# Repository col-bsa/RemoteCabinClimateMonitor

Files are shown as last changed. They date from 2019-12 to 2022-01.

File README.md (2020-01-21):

# RemoteCabinClimateMonitor

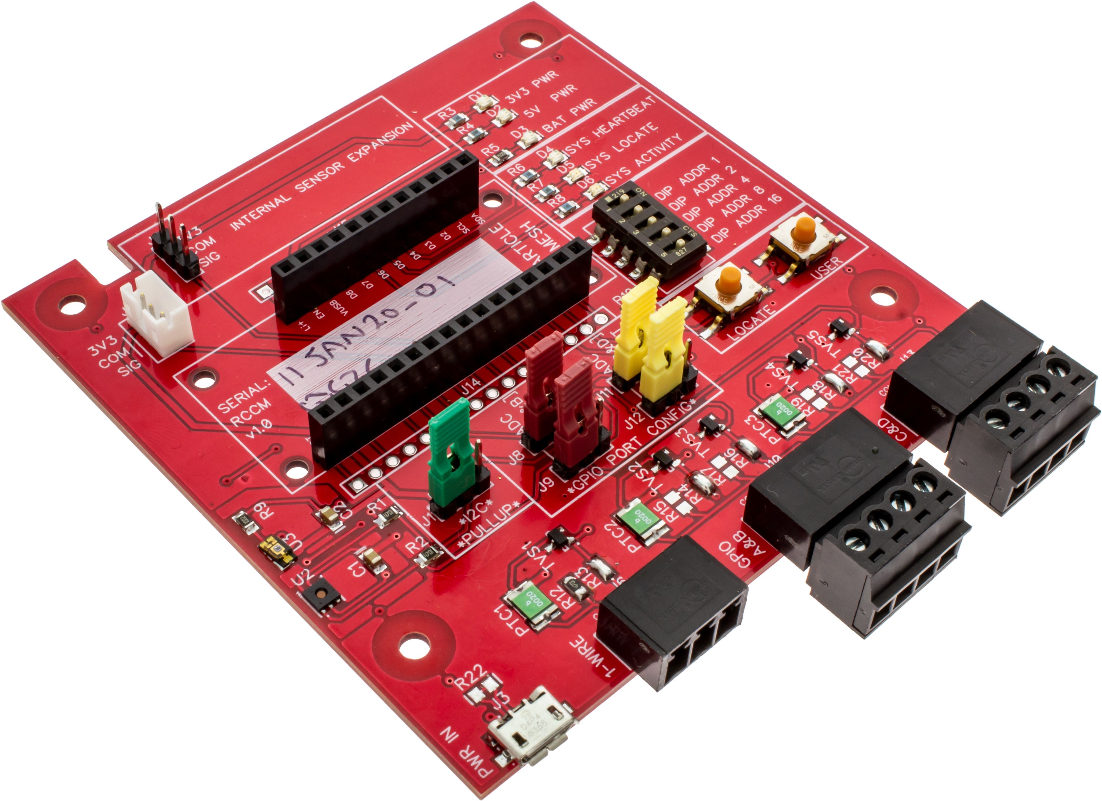
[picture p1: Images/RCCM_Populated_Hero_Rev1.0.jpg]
Remote Cabin Climate Monitor


A Particle Mesh based environmental sensor board, whose primary purpose is to monitor unoccupied cabin temperatures at Resica Falls Scout Reservation.

Repository Contents
-------------------

* **/Hardware** - DipTrace Schematic & PCB Layout
* **/Software** - 
* **/Images** -

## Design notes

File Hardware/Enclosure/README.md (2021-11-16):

# RCCM Enclosure

Designed in Fusion360.

Designed for FDM 3D Printing:
- Prusa MK3S
- Prusament PLA (Galaxy Black)
- Prusa Slicer 0.2mm DETAIL Preset

Current Design:
https://a360.co/3HgQXV9

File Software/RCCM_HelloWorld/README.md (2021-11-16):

# RCCM_HelloWorld

Quick and dirty firmware for "end of line" function RCCM PCB finctionality.

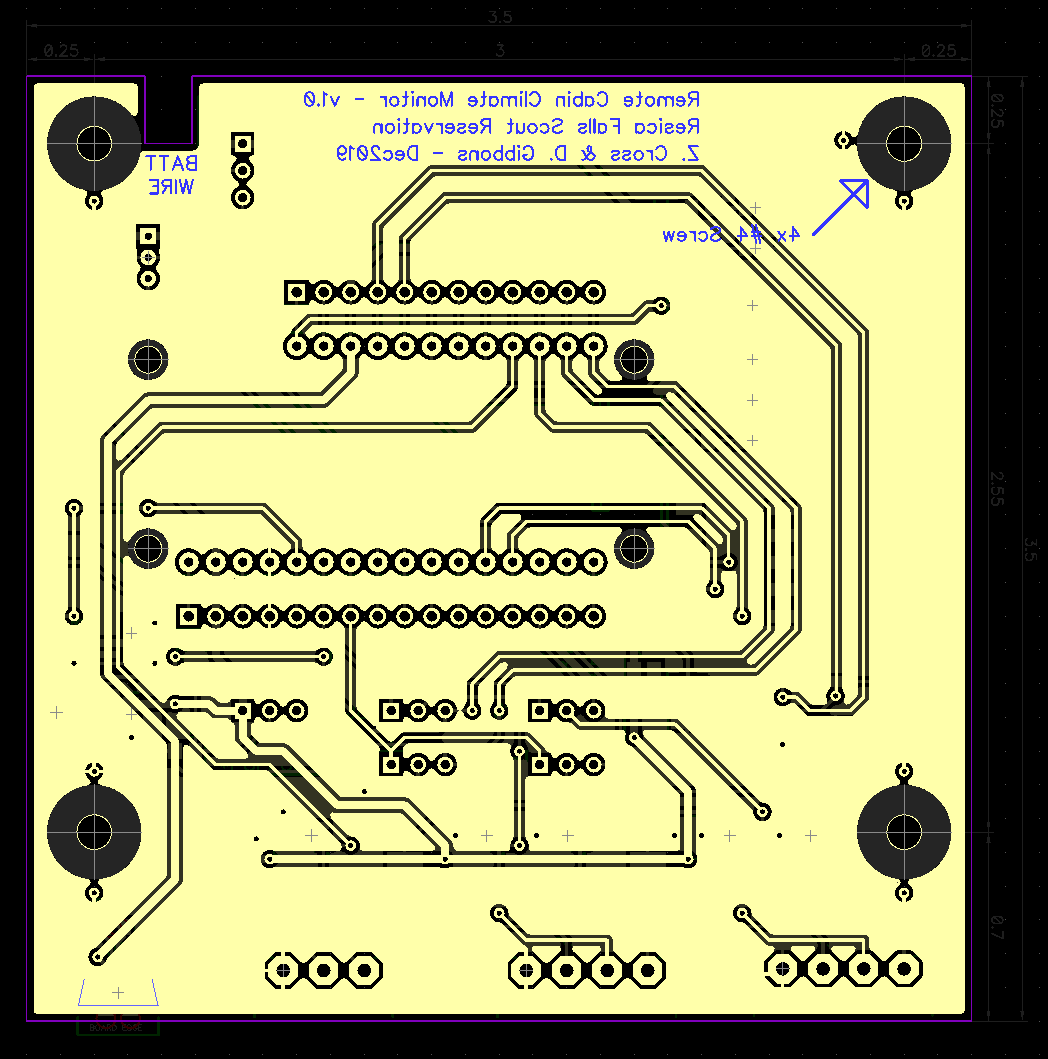
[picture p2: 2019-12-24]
Images/RCCM_PCB_Layout_Back_Rev1.0.png

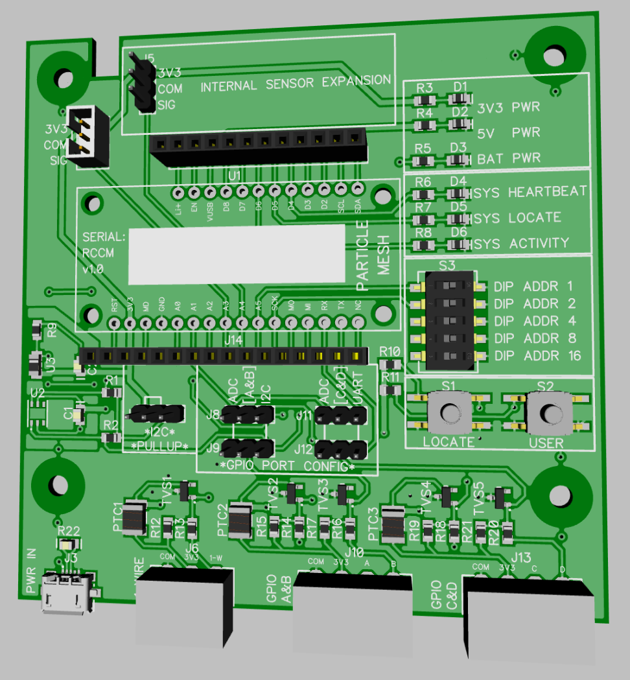
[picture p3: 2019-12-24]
Images/RCCM_PCB_3DModel_Front_Rev1.0.png

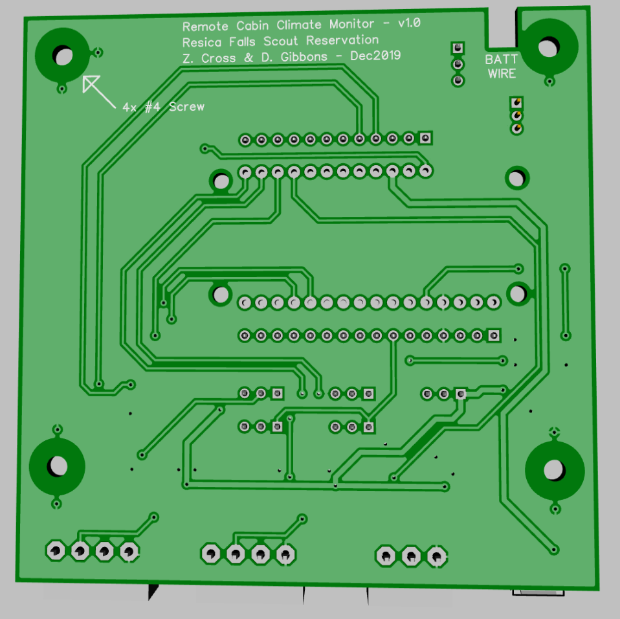
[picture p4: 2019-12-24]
Images/RCCM_PCB_3DModel_Back_Rev1.0.png

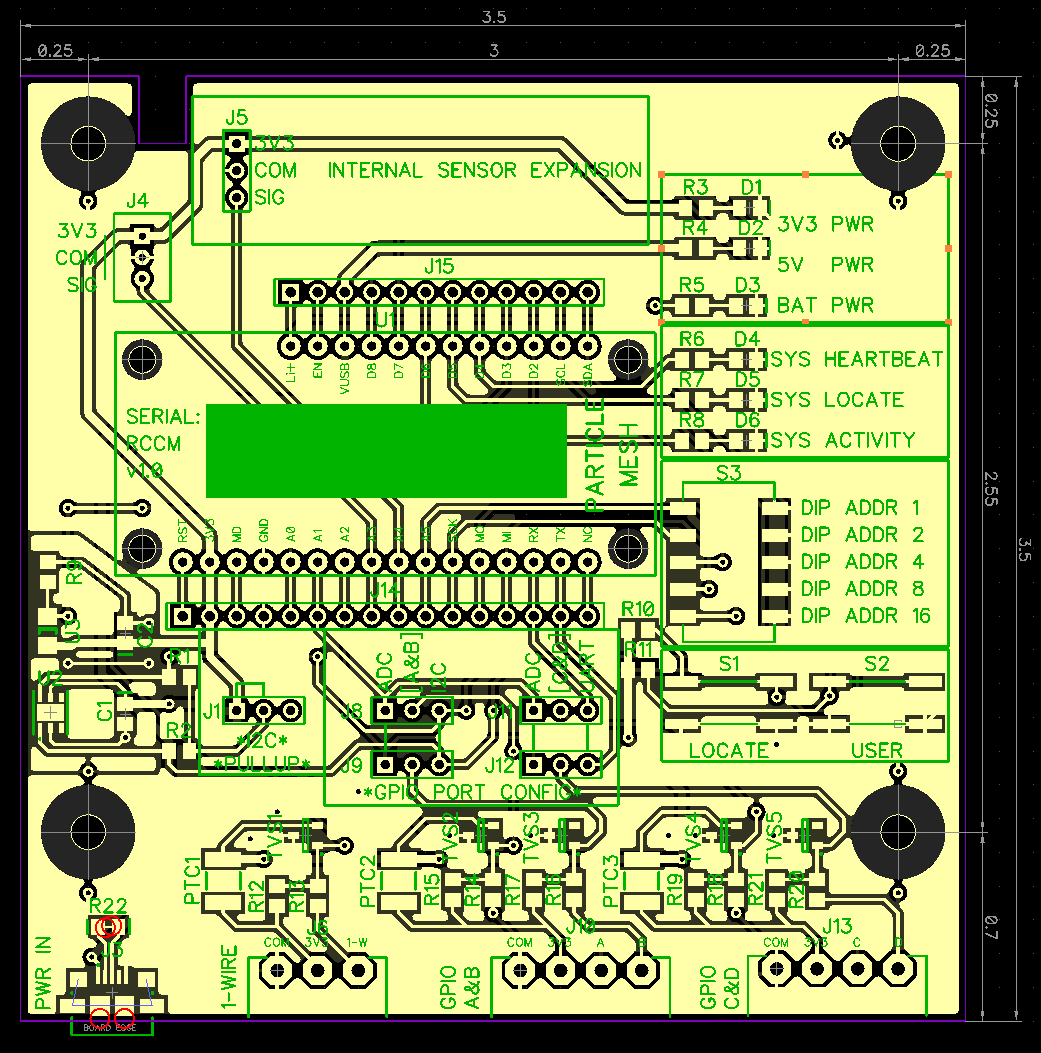
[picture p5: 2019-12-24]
Images/RCCM_PCB_Layout_Front_Rev1.0.png

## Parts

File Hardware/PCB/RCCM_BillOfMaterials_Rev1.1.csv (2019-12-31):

# | Name | RefDes | Manufacturer | Mfr Pn | Cost
1 | CAP CER 0.1UF 100V X7R 0805 | C1 | Samsung Electro-Mechanics | CL21B104KCFNNNE | 0.1
2 | CAP CER 0.1UF 100V X7R 0805 | C2 | Samsung Electro-Mechanics | CL21B104KCFNNNE | 0.1
3 | LED YELLOW/GREEN CLEAR 0805 SMD | D1 | Everlight Electronics Co Ltd | 17-21SYGC/S530-E2/TR8 | 0.29
4 | LED YELLOW/GREEN CLEAR 0805 SMD | D2 | Everlight Electronics Co Ltd | 17-21SYGC/S530-E2/TR8 | 0.29
5 | LED YELLOW/GREEN CLEAR 0805 SMD | D3 | Everlight Electronics Co Ltd | 17-21SYGC/S530-E2/TR8 | 0.29
6 | LED YELLOW/GREEN CLEAR 0805 SMD | D4 | Everlight Electronics Co Ltd | 17-21SYGC/S530-E2/TR8 | 0.29
7 | LED ORANGE-RED 0805 SMD | D5 | Dialight | 5990120007F | 0.38
8 | LED ORANGE-RED 0805 SMD | D6 | Dialight | 5990120007F | 0.38
9 | S1012EC-03-ND | J1 | Sullins Connector Solutions | PREC003SAAN-RC | 0.09
10 | TERM BLOCK PLUG 4POS STR 3.81MM | J2 | Molex | 0395100004 | 1.71
11 | CONN RCPT USB2.0 MICRO B SMD R/A | J3 | TE Connectivity | 1981568-1 | 1.86
12 | CONN HEADER VERT 3POS 2MM | J4 | JST Sales America Inc. | B3B-PH-K-S(LF)(SN) | 0.19
13 | S1012EC-03-ND | J5 | Sullins Connector Solutions | PREC003SAAN-RC | 0.09
14 | TERM BLOCK HDR 3POS 90DEG 3.81MM BLACK | J6 | Molex | 0395121003 | 1.03
15 | TERM BLOCK PLUG 3POS STR 3.81MM BLACK | J7 | Molex | 0395100003 | 1.25
16 | S1012EC-03-ND | J8 | Sullins Connector Solutions | PREC003SAAN-RC | 0.09
17 | S1012EC-03-ND | J9 | Sullins Connector Solutions | PREC003SAAN-RC | 0.09
18 | TERM BLOCK HDR 4POS 90DEG 3.81MM BLACK | J10 | Molex | 0395121004 | 1.41
19 | S1012EC-03-ND | J11 | Sullins Connector Solutions | PREC003SAAN-RC | 0.09
20 | S1012EC-03-ND | J12 | Sullins Connector Solutions | PREC003SAAN-RC | 0.09
21 | TERM BLOCK HDR 4POS 90DEG 3.81MM BLACK | J13 | Molex | 0395121004 | 1.41
22 | CONN HDR 16POS 0.1 TIN PCB | J14 | Sullins | PPTC161LFBN-RC | 0.98
23 | CONN HDR 12POS 0.1 TIN PCB | J15 | Sullins | PPTC121LFBN-RC | 0.78
24 | TERM BLOCK PLUG 4POS STR 3.81MM | J16 | Molex | 0395100004 | 1.71
25 | CONN SHUNT | JMP1 | Samtec Inc. | SNT-100-BK-T | 0.21
26 | CONN SHUNT | JMP2 | Samtec Inc. | SNT-100-BK-T | 0.21
27 | CONN SHUNT | JMP3 | Samtec Inc. | SNT-100-BK-T | 0.21
28 | CONN SHUNT | JMP4 | Samtec Inc. | SNT-100-BK-T | 0.21
29 | CONN SHUNT | JMP5 | Samtec Inc. | SNT-100-BK-T | 0.21
30 | PTC RESET FUSE 30V 200MA 1812 | PTC1 | Littelfuse Inc. | Fuse | 0.42
31 | PTC RESET FUSE 30V 200MA 1812 | PTC2 | Littelfuse Inc. | Fuse | 0.42
32 | PTC RESET FUSE 30V 200MA 1812 | PTC3 | Littelfuse Inc. | Fuse | 0.42
33 | CRGH0805 1% 4K7 0.33W | R1 | TE Connectivity Passive Product | CRGH0805F4K7 | 0.1
34 | CRGH0805 1% 4K7 0.33W | R2 | TE Connectivity Passive Product | CRGH0805F4K7 | 0.1
35 | 130 Ohms ±1% 0.25W, 1/4W Chip Resistor 0805 | R3 | KOA Speer Electronics, Inc. | RK73H2ATTD1300F | 0.1
36 | 300 Ohms ±1% 0.25W, 1/4W Chip Resistor 0805 | R4 | KOA Speer Electronics, Inc. | RK73H2ATTD3000F | 0.1
37 | RES SMD 150 OHM 1% 1/3W 0805 | R5 | TE Connectivity Passive Product | CRGH0805F150R | 0.1
38 | 130 Ohms ±1% 0.25W, 1/4W Chip Resistor 0805 | R6 | KOA Speer Electronics, Inc. | RK73H2ATTD1300F | 0.1
39 | 130 Ohms ±1% 0.25W, 1/4W Chip Resistor 0805 | R7 | KOA Speer Electronics, Inc. | RK73H2ATTD1300F | 0.1
40 | 130 Ohms ±1% 0.25W, 1/4W Chip Resistor 0805 | R8 | KOA Speer Electronics, Inc. | RK73H2ATTD1300F | 0.1
41 | RES SMD 10K OHM 1% 1/3W 0805 | R9 | TE Connectivity Passive Product | CRGH0805F10K | 0.11
42 | RES SMD 10K OHM 1% 1/3W 0805 | R10 | TE Connectivity Passive Product | CRGH0805F10K | 0.11
43 | RES SMD 10K OHM 1% 1/3W 0805 | R11 | TE Connectivity Passive Product | CRGH0805F10K | 0.11
44 | CRGH0805 1% 4K7 0.33W | R12 | TE Connectivity Passive Product | CRGH0805F4K7 | 0.1
45 | RES SMD 10K OHM 1% 1/3W 0805 | R13 | TE Connectivity Passive Product | CRGH0805F10K | 0.11
46 | RES SMD 10K OHM 1% 1/3W 0805 | R14 | TE Connectivity Passive Product | CRGH0805F10K | 0.11
47 | RES SMD 10K OHM 1% 1/3W 0805 | R15 | TE Connectivity Passive Product | CRGH0805F10K | 0.11
48 | RES SMD 10K OHM 1% 1/3W 0805 | R16 | TE Connectivity Passive Product | CRGH0805F10K | 0.11
49 | RES SMD 10K OHM 1% 1/3W 0805 | R17 | TE Connectivity Passive Product | CRGH0805F10K | 0.11
50 | RES SMD 10K OHM 1% 1/3W 0805 | R18 | TE Connectivity Passive Product | CRGH0805F10K | 0.11
51 | RES SMD 10K OHM 1% 1/3W 0805 | R19 | TE Connectivity Passive Product | CRGH0805F10K | 0.11
52 | RES SMD 10K OHM 1% 1/3W 0805 | R20 | TE Connectivity Passive Product | CRGH0805F10K | 0.11
53 | RES SMD 10K OHM 1% 1/3W 0805 | R21 | TE Connectivity Passive Product | CRGH0805F10K | 0.11
54 | JMP_0805 | R22
55 | SWITCH TACTILE SPST-NO 0.01A 32V | S1 | C&K | KSC443G70SHLFG | 0.87
56 | SWITCH TACTILE SPST-NO 0.01A 32V | S2 | C&K | KSC443G70SHLFG | 0.87
57 | SWITCH SLIDE DIP SPST 100MA 20V | S3 | CTS Electrocomponents | 219-5MST | 0.82
58 | TVS DIODE 3.3V 10V SOT323 | TVS1 | Diodes Incorporated | D1213A-01W-7 | 0.36
59 | TVS DIODE 3.3V 10V SOT323 | TVS2 | Diodes Incorporated | D1213A-01W-7 | 0.36
60 | TVS DIODE 3.3V 10V SOT323 | TVS3 | Diodes Incorporated | D1213A-01W-7 | 0.36
61 | TVS DIODE 3.3V 10V SOT323 | TVS4 | Diodes Incorporated | D1213A-01W-7 | 0.36
62 | TVS DIODE 3.3V 10V SOT323 | TVS5 | Diodes Incorporated | D1213A-01W-7 | 0.36
63 | Particle Xenon IoT Development Board | U1 | Particle | WRL-15070 | 15
64 | SENS HUMID/TEMP 3.6V I2C 3% 6DFN | U2 | Silicon Labs | SI7021-A20-GMR | 3.06
65 | SENSOR PHOTO 570NM TOP VIEW 1206 | U3 | Vishay Semiconductor Opto Division | TEMT6000X01 | 1.53
66 | SparkFun OpenPIR | U4 | SparkFun | SEN-1396 | 15.95
67 | JST Jumper 3 Wire Assembly | U5 | SparkFun | PRT-09915 | 1.50
68 | Lithium Ion Battery - 2Ah | Ux | SparkFun | PRT-13855 | 12.95

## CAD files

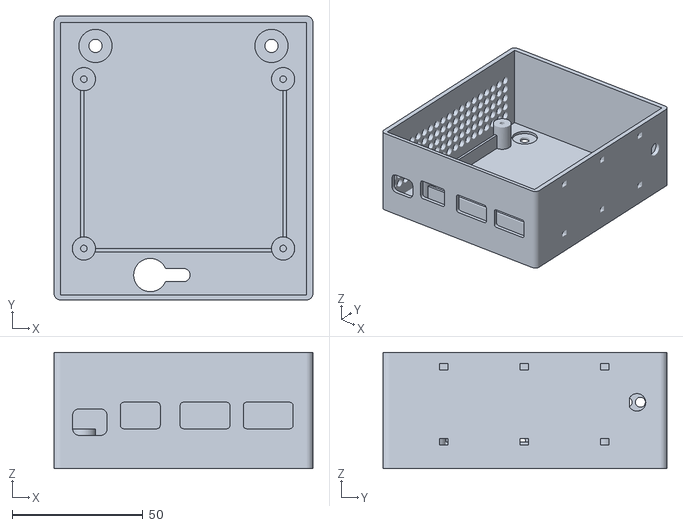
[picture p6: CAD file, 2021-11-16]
Hardware/Enclosure/RCCM_Enclosure_Main Bosy.stl
99.1 x 108.6 x 44.5

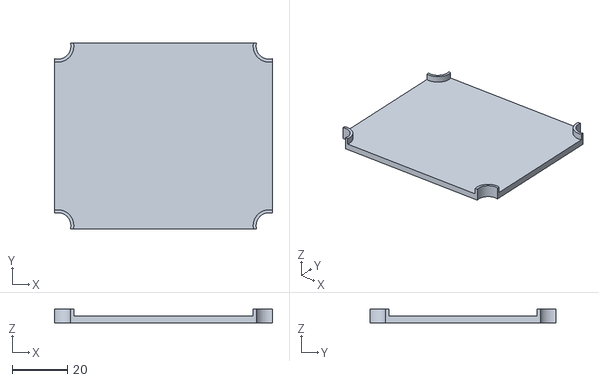
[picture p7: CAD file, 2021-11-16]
Hardware/Enclosure/RCCM_Enclosure_Battery Cover.stl
78.7 x 67.3 x 5.08

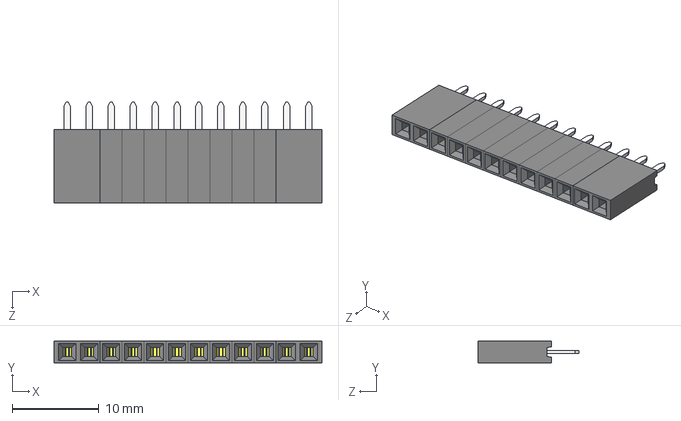
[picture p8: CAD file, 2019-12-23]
Hardware/PCB/Component_3D_Models_And_Libraries/hdrf-1x12t_2.54_31x3.step
31.0 x 2.50 x 11.7 mm

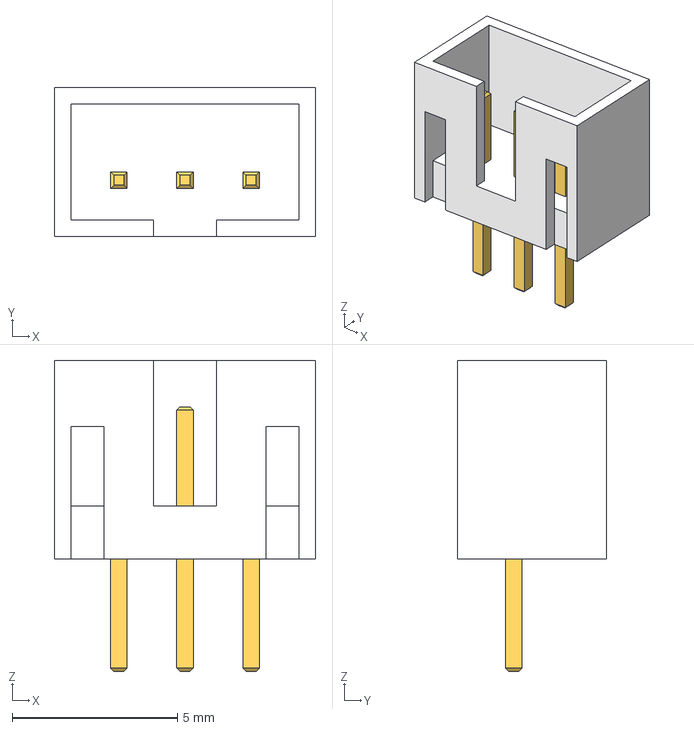
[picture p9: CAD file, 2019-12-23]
Hardware/PCB/Component_3D_Models_And_Libraries/Misc/JST Socket 3 Pin.step
7.90 x 4.50 x 9.40 mm

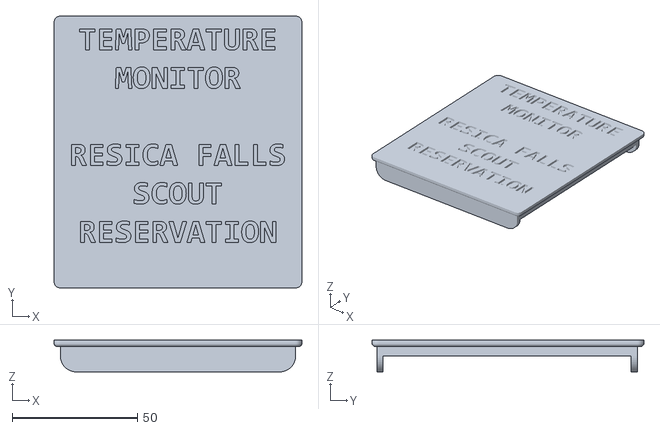
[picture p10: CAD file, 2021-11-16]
Hardware/Enclosure/RCCM_Enclosure_Lid.stl
99.1 x 108.6 x 12.7

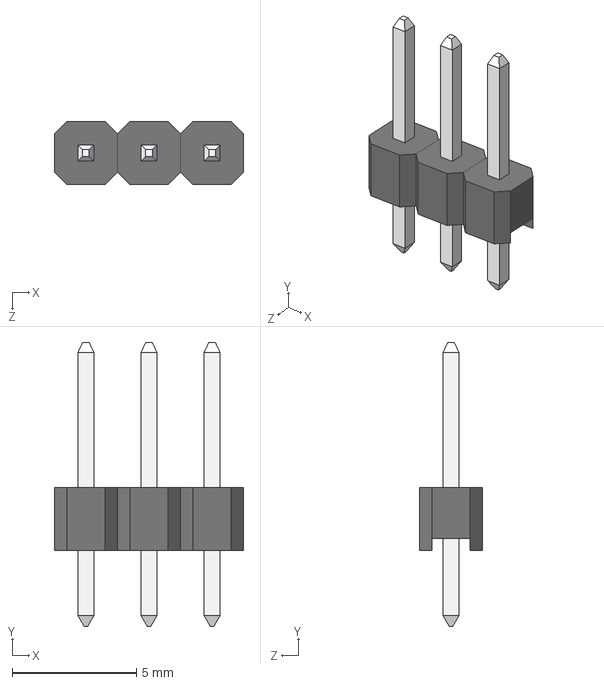
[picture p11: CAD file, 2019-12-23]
Hardware/PCB/Component_3D_Models_And_Libraries/PREC003SAAN-RC.STEP
7.62 x 11.4 x 2.54 mm
1 row end bumps format x 3

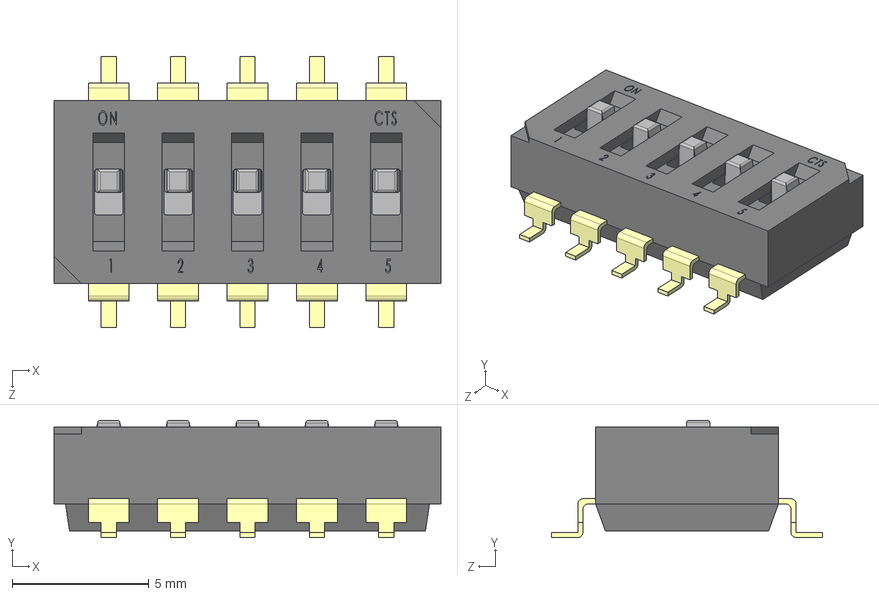
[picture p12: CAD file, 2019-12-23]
Hardware/PCB/Component_3D_Models_And_Libraries/219-5poles.stp
14.2 x 4.30 x 9.91 mm

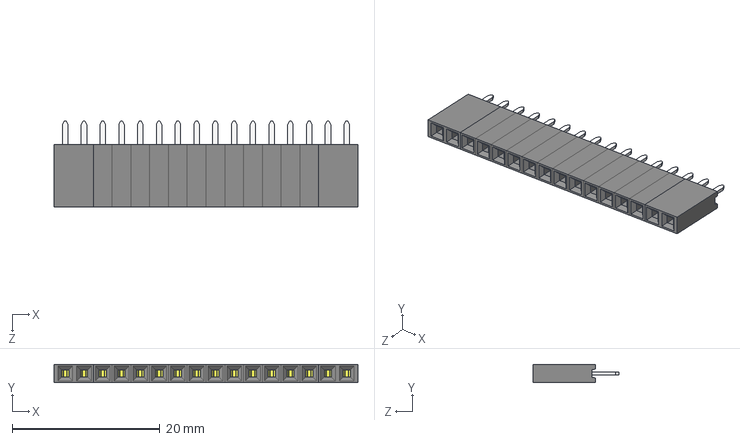
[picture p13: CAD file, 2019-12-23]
Hardware/PCB/Component_3D_Models_And_Libraries/hdrf-1x16t_2.54_41x3.step
41.1 x 2.50 x 11.7 mm

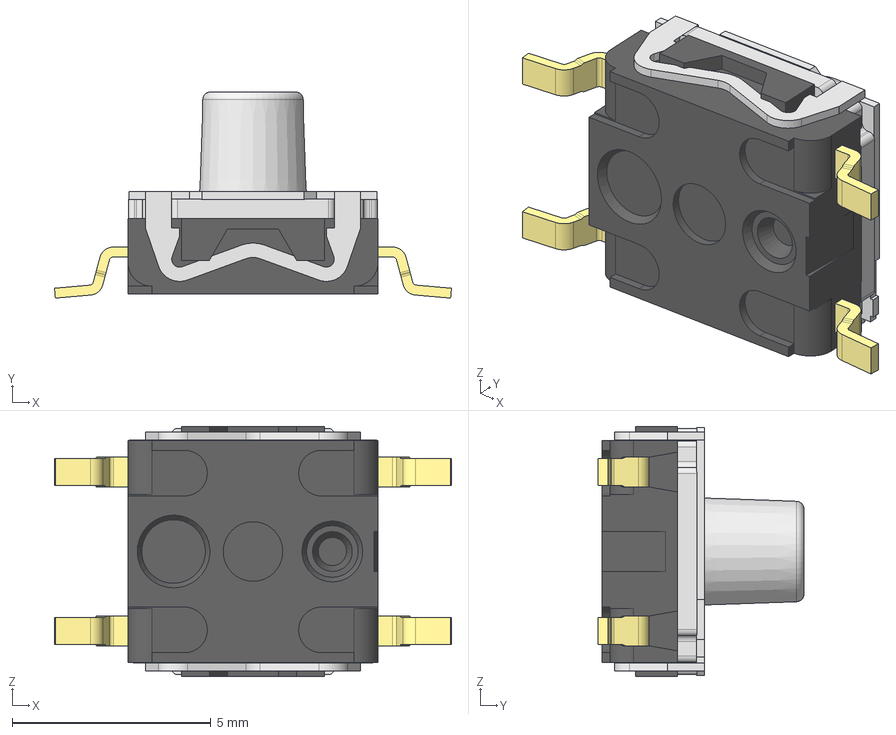
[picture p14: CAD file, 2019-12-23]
Hardware/PCB/Component_3D_Models_And_Libraries/KSC443G70SHLFG.stp
10.00 x 5.19 x 6.30 mm
_KSC4 - body
_KSC4 - button
_KSC4 - cover
_KSC43G_pin x 4

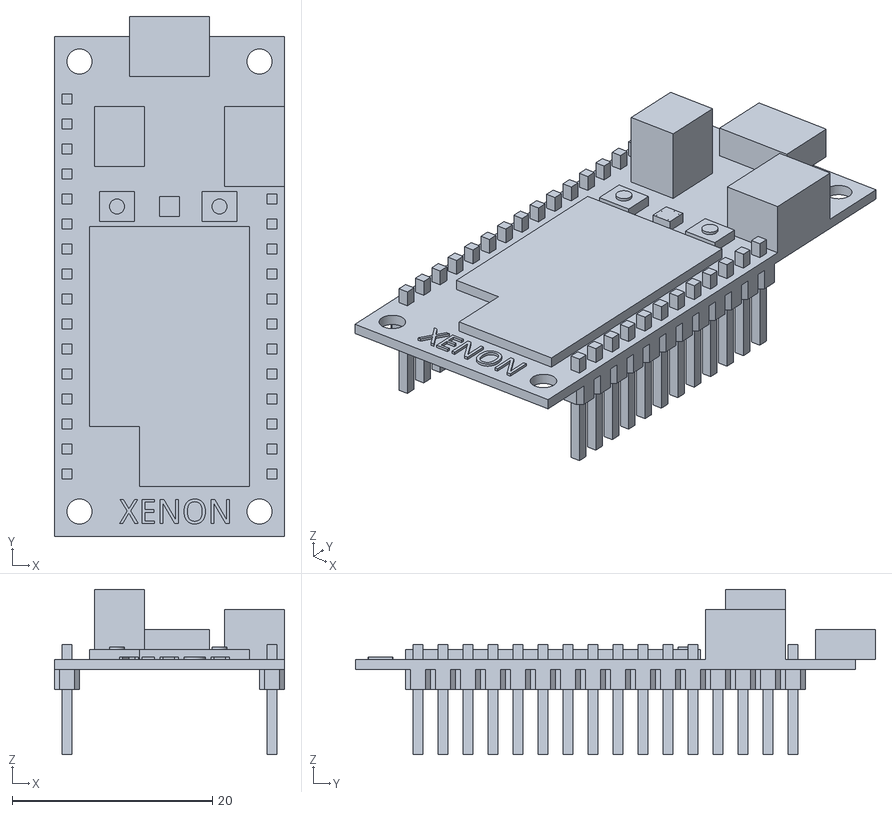
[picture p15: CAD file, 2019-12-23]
Hardware/PCB/Component_3D_Models_And_Libraries/Particle_Mesh_Xenon.stl
23.0 x 52.0 x 16.5

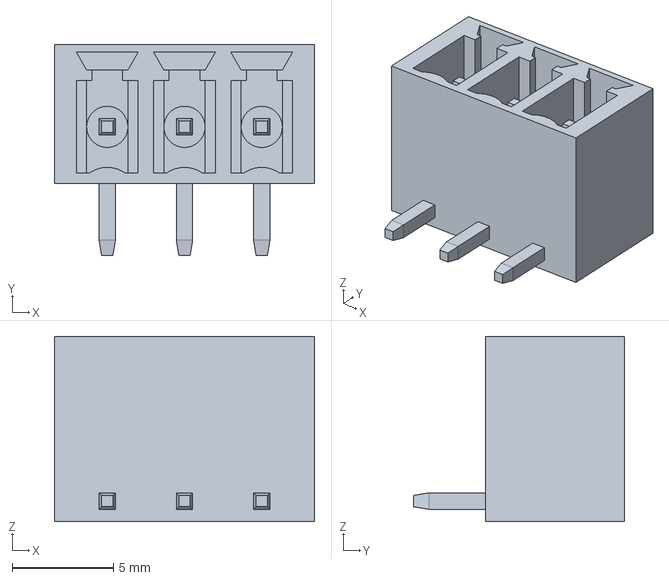
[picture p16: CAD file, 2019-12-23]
Hardware/PCB/Component_3D_Models_And_Libraries/395121003.stp
12.8 x 10.4 x 9.14 mm

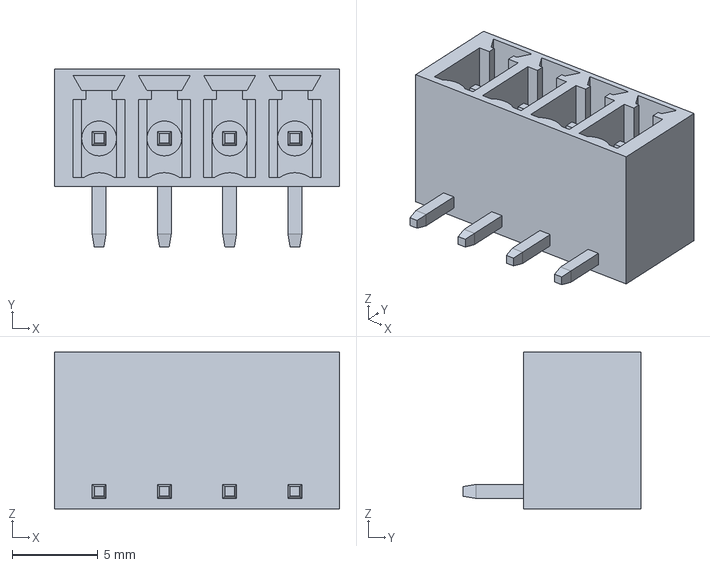
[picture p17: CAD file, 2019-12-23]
Hardware/PCB/Component_3D_Models_And_Libraries/395121004.stp
16.6 x 10.4 x 9.14 mm

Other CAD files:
Hardware/Enclosure/RCCM_Enclosure v30.f3z

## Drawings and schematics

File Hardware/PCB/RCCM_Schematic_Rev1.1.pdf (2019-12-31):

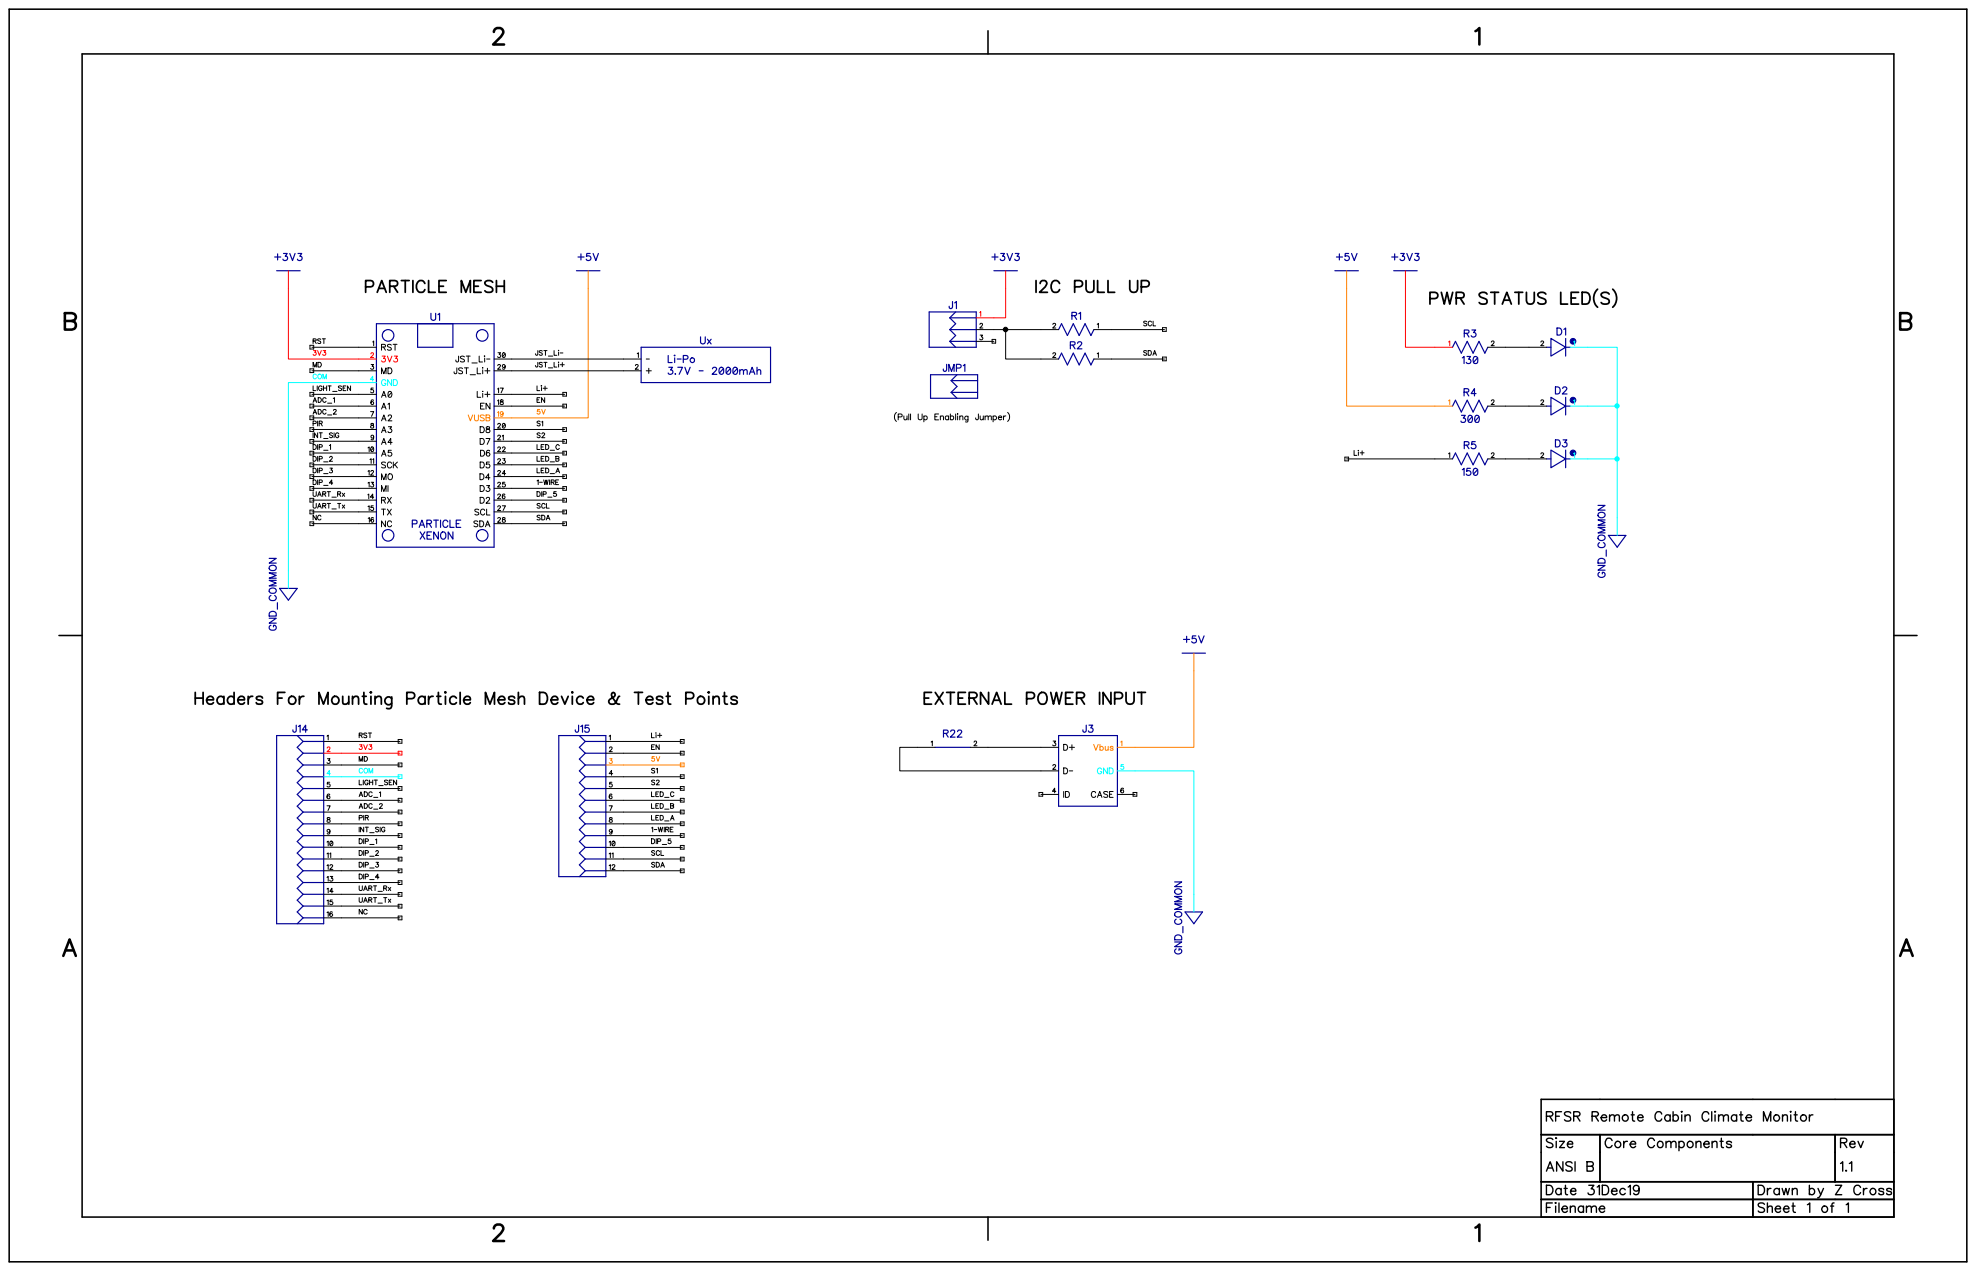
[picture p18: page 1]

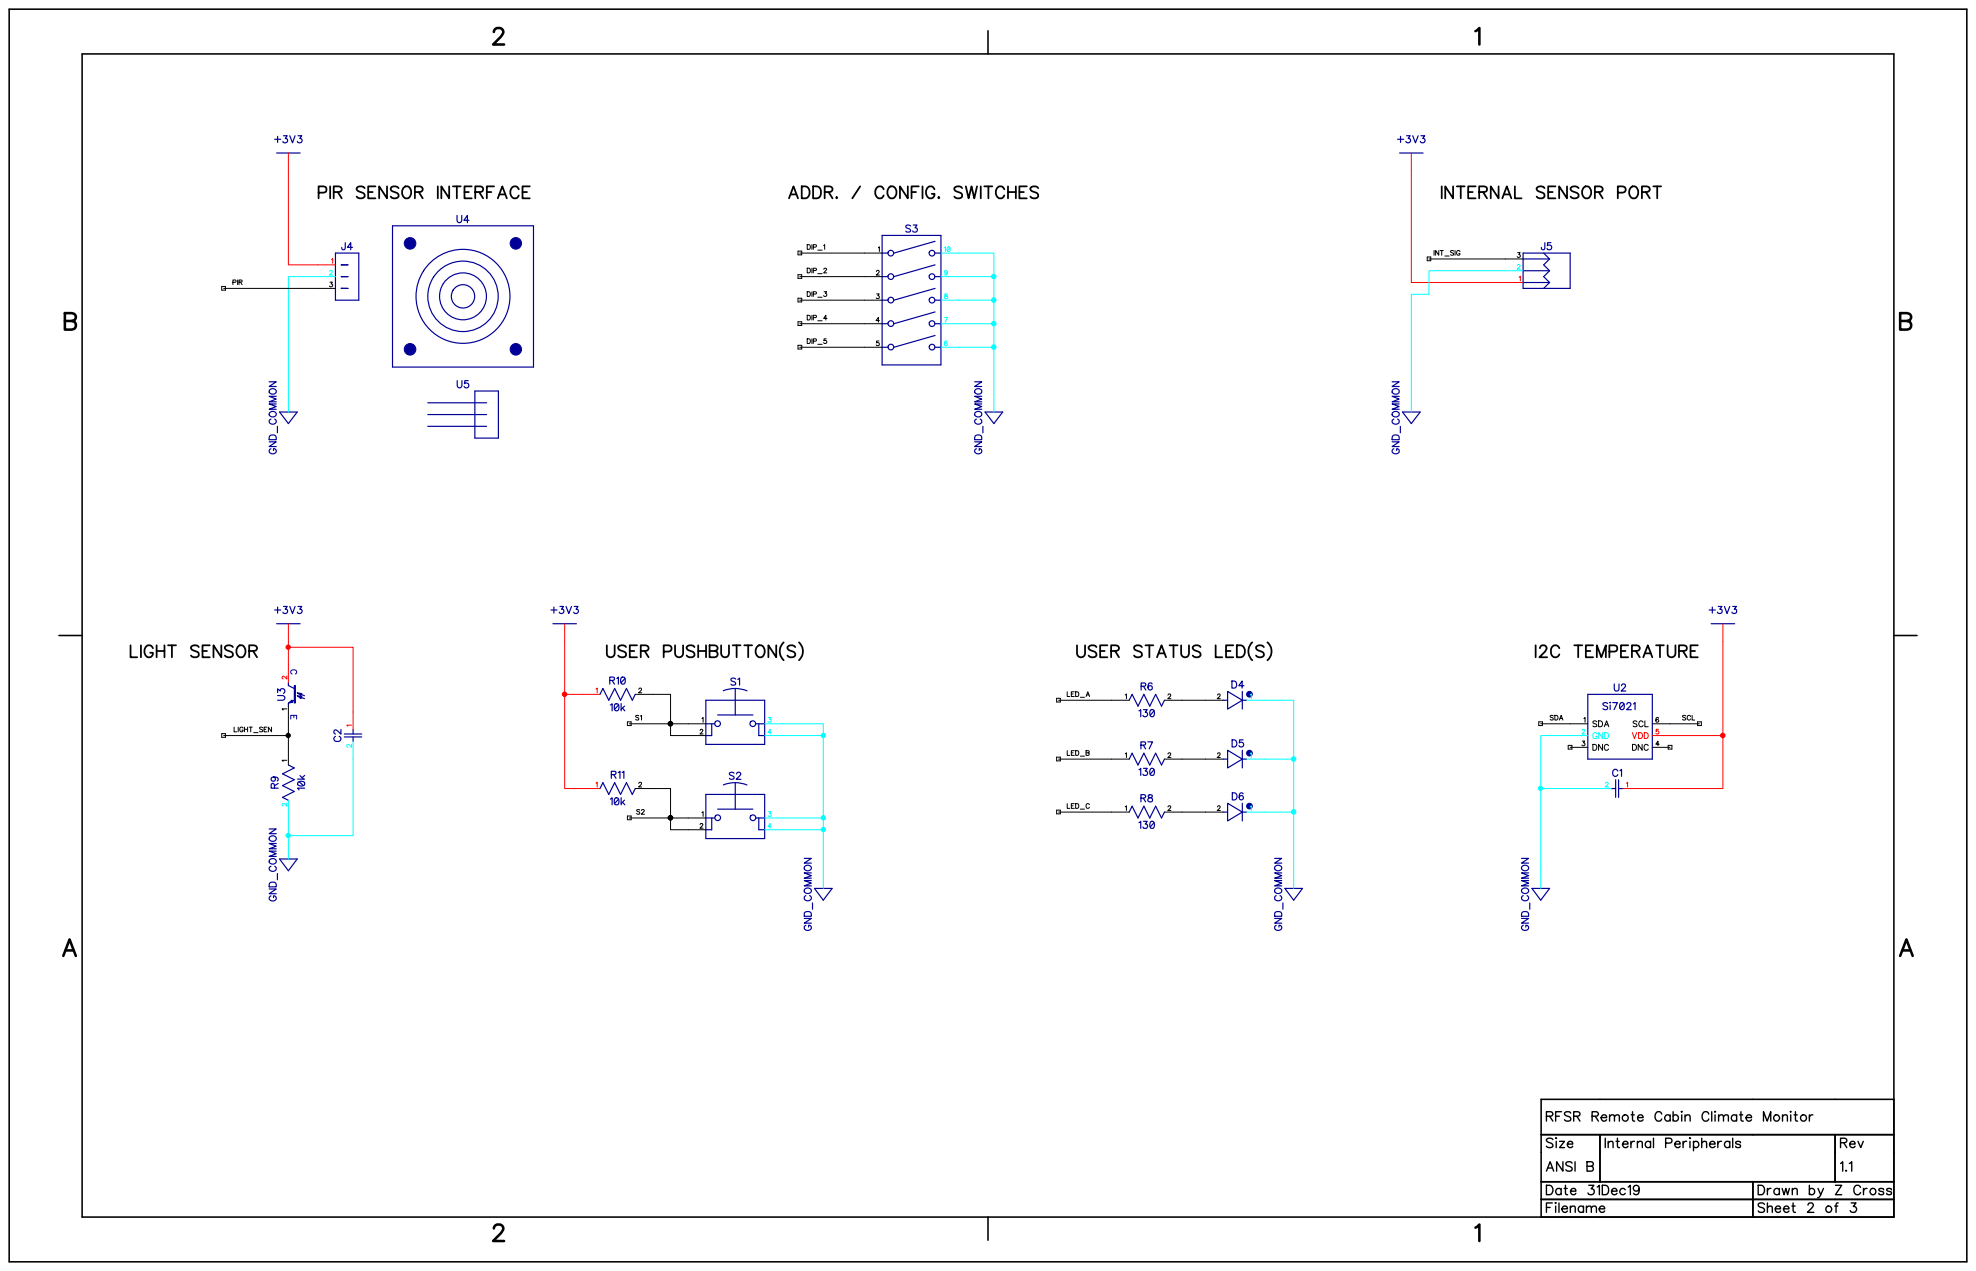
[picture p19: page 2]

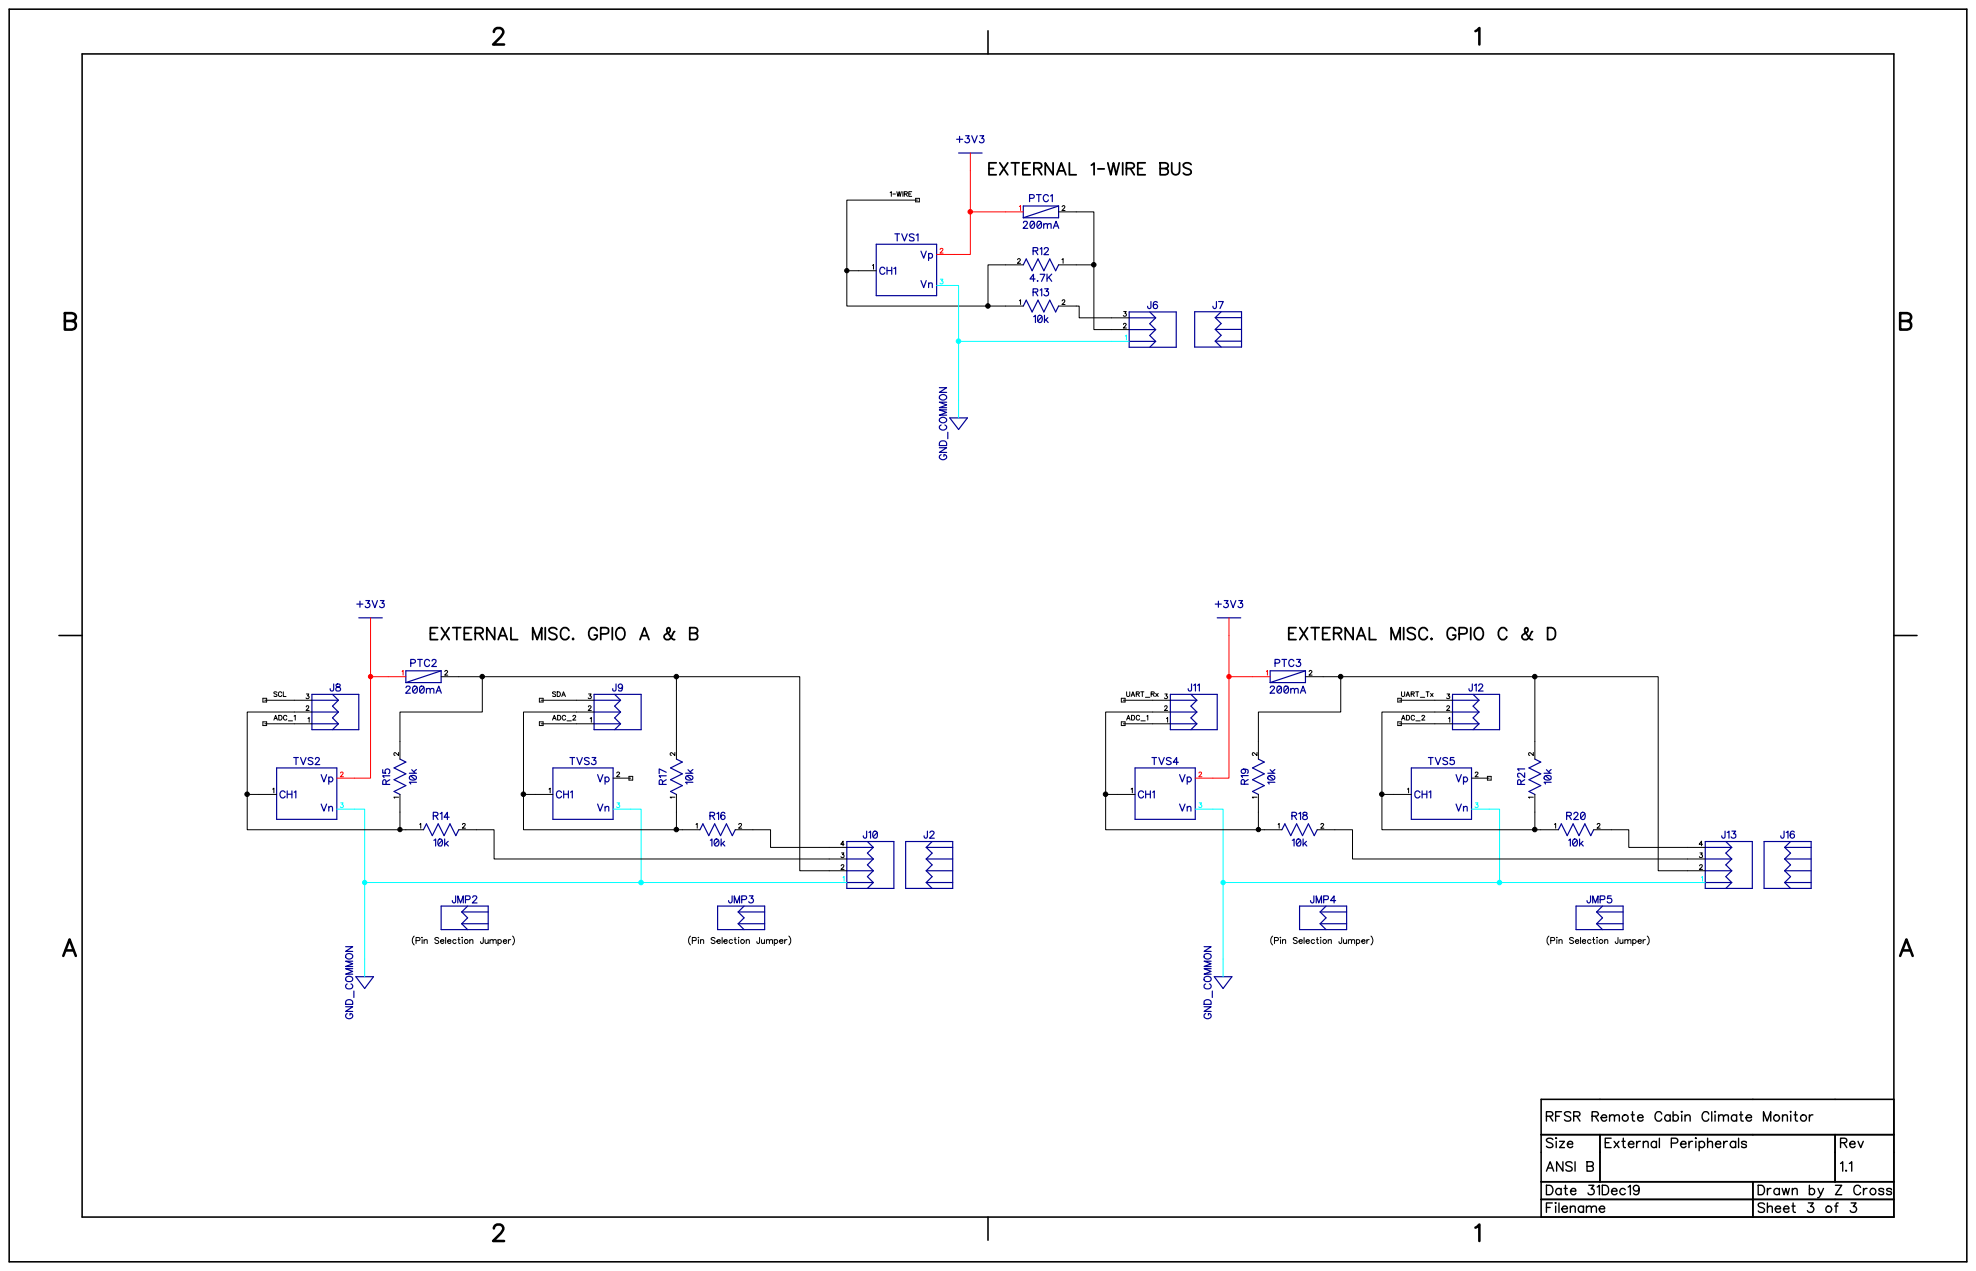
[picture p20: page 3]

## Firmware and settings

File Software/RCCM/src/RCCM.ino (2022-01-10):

/*
 * Project: Remote Cabin Climate Monitor (RCCM)
 * Description: A Particle Mesh based environmental sensor board, whose primary purpose is to monitor unoccupied cabin temperatures at Resica Falls Scout Reservation.
 * Author: Z. Cross
 * Date: Oct2021
 */


// === STATIC CONFIGURATION ===
#define FW_VERSION      	"0.1.4"

// Timer; not currently in use.
#define INTERVAL_ENVIRONMENT_DATA_DELAY_MS      15000     // 15 Seconds 

#define THRESH_TEMP_LOW     40
#define THRESH_TEMP_HIGH    95
#define THRESH_TEMP_DELTA   0.2
#define THRESH_BATT_LOW     25

#define INTERNAL_COLLECTION_INTERVAL    (60*15)            // 15 Minutes
#define HEARTBEAT_INTERVAL              (60*60*24)         // 1 Day

#define ALERT_THROTTLE_DELAY            1010               // ms


// === PCB PINPOUT DEFINITIONS ===
#define PIN_LIGHT_SEN     19  // Internal Light Sensor Signal (Analog)
#define PIN_ADC_1         18  // External GPIO Port Signal
#define PIN_ADC_2         17  // External GPIO Port Signal
#define PIN_PIR           16  // PIR Sensor Port Signal
#define PIN_INT_SIG       15  // Internal Sensor Port Signal
#define PIN_DIP_1         14  // Internal DIP Switch Position 1
#define PIN_DIP_2         13  // Internal DIP Switch Position 2
#define PIN_DIP_3         12  // Internal DIP Switch Position 3
#define PIN_DIP_4         11  // Internal DIP Switch Position 4
#define PIN_UART_Rx       10  // External UART Port Signal Rx
#define PIN_UART_Tx       9   // External UART Port Signal Tx

#define PIN_S1            8   // Internal Pushbutton S1
#define PIN_S2            7   // Internal Pushbutton S2
#define PIN_LED_HEARTB    4   // Internal Heartbeat LED (Green)
#define PIN_LED_LOCATE    5   // Internal Locate LED (Red)
#define PIN_LED_ACTIVITY  6   // Internal Activity LED (Red)
#define PIN_1W            3   // External 1-Wire Bus Signal
#define PIN_DIP_5         2   // Internal DIP Switch Position 5


// === INTERNAL MACROS ===
#define C_TO_F(celsius)     (((celsius) * 1.8) + 32)


// === INCLUDES ===
#include <DataLog.h>
#include <Adafruit_Si7021.h>
#include <JsonParserGeneratorRK.h>
#include <LocalTimeRK.h>
#include "secrets.h"


// === GLOBAL OBJECTS ===
DataLog         dataLog(100);
Adafruit_Si7021 Si7021 = Adafruit_Si7021();     // Onboard I2C Temp & Humidity Sensor
FuelGauge       fuel;                           // Onboard Battery Fuel Gauge


// === TIMERS ===
Timer tCollectEnvironmentData(INTERVAL_ENVIRONMENT_DATA_DELAY_MS, timer_interval_environment_data);    


// === GLOBAL STRUCT / ENUM DEFINITIONS ===
// Reasons to generate user alert.
struct alertList {
    bool bTempLow;
    bool bTempHigh;
    bool bTempDelta;
    bool bTempClear;
    bool bPowerLoss;
    bool bPowerRestore;
    bool bBatteryLow;
    bool bHeartbeat;
};

// Environmental Data Collected
struct environmentData {
    long        time;
    String      timeString;
    bool        timeValid;
    double      batteryCharge;
    int32_t     batteryState;
    int32_t     powerSource;
    double      temperatureF;
    double      humidity;    
    int32_t     lightLevel;
};


// === GLOBAL VARIABLES ===
const String    sFwVersion                          = FW_VERSION;
bool            bCollectIntervalEnvironmentData     = false;
float           fThreshTempLow                      = THRESH_TEMP_LOW;
float           fThreshTempHigh                     = THRESH_TEMP_HIGH;
float           fThreshTempDelta                    = THRESH_TEMP_DELTA;
bool            bCurrentTempAlert                   = false;
float           fThreshBattLow                      = THRESH_BATT_LOW;
struct environmentData  environmentDataInterval;
struct environmentData  environmentDataLastInterval;
struct alertList        activeAlertsInterval;
struct alertList        activeAlertsLastInterval;


// === PARTICLE CONFIGURATION ===
//SYSTEM_MODE(SEMI_AUTOMATIC);
//SYSTEM_THREAD(ENABLED);

// 
void setup() {
    // Particle Cloud Variable Registration
    Particle.variable("sFwVersion", sFwVersion);
    Particle.variable("battCharge", environmentDataInterval.batteryCharge);
    Particle.variable("battState", environmentDataInterval.batteryState);
    Particle.variable("humidity", environmentDataInterval.humidity);
    Particle.variable("lightLevel", environmentDataInterval.lightLevel);
    Particle.variable("pwrSrc", environmentDataInterval.powerSource);
    Particle.variable("tempF", environmentDataInterval.temperatureF);
    Particle.variable("time", environmentDataInterval.time);
    Particle.variable("timeStr", environmentDataInterval.timeString);
    Particle.variable("timeVal", environmentDataInterval.timeValid);

    // Particle Cloud Function Registration
    Particle.function("collect_environment_data", collect_environment_data);
    Particle.function("publish_alert", publish_alert);

    // I/O
        // Internal Sensor Expansion
        pinMode(PIN_INT_SIG, INPUT);

        // PIR Sensor
        pinMode(PIN_PIR, INPUT);

        // Internal Switches
        pinMode(PIN_DIP_1,  INPUT_PULLUP);
        pinMode(PIN_DIP_2,  INPUT_PULLUP);
        pinMode(PIN_DIP_3,  INPUT_PULLUP);
        pinMode(PIN_DIP_4,  INPUT_PULLUP);
        pinMode(PIN_DIP_5,  INPUT_PULLUP);
        pinMode(PIN_S1,     INPUT_PULLUP);
        pinMode(PIN_S2,     INPUT_PULLUP);

        // Internal Status LEDs
        pinMode(PIN_LED_HEARTB,     OUTPUT);
        pinMode(PIN_LED_LOCATE,     OUTPUT);
        pinMode(PIN_LED_ACTIVITY,   OUTPUT);

        // Internal Sensor Interfaces
        pinMode(PIN_PIR,        INPUT_PULLUP);
        pinMode(PIN_INT_SIG,    INPUT_PULLUP);

        // External Sensor Interfaces
        pinMode(PIN_ADC_1,  INPUT_PULLUP);
        pinMode(PIN_ADC_2,  INPUT_PULLUP);
        pinMode(PIN_1W,     INPUT_PULLUP);


    // Debug UART
    Serial.begin(115200);
    Serial.println("=== REMOTE CABIN CLIMATE MONITOR ===");
    Serial.println(FW_VERSION);

    // Set time zone to Eastern USA daylight saving time
    Time.zone(-4);
    // (https://docs.particle.io/cards/libraries/l/LocalTimeRK/), does not modify base Time class timezone!
    LocalTime::instance().withConfig(LocalTimePosixTimezone("EST5EDT,M3.2.0/2:00:00,M11.1.0/2:00:00"));

    // Local Temp & Humidity Sensor
    Si7021.begin();

    // Ephemeral Debug Log Message
    Particle.publish("RCCM_Debug: Setup Function");
    
    // Publish Startup Alert
    collect_environment_data(" ");
    publish_alert("SYS_STARTUP");

}   // END setup


// 
void loop() {
    // Local Variable Declarations
    //float fTempDelta;
    static long  lLastDataCollectTime = 0;
    static long  lLastHeartbeatTime   = 0;


    // === TASK SCHEDULING ===
    if (Time.now() >= (lLastDataCollectTime + INTERNAL_COLLECTION_INTERVAL)) {
        lLastDataCollectTime = Time.now();
        bCollectIntervalEnvironmentData = true;

    }


    // === TASK ===
    // Collect interval environment data.  (Timer flag based.)
    if (bCollectIntervalEnvironmentData == true) {
        // Ephemeral Debug Log Message
        Particle.publish("RCCM_Debug: Collect Internal Environment Data");

        // Store current data as last for delta based alert comparison.
        environmentDataLastInterval = environmentDataInterval;

        // Collect New Data
        collect_environment_data(" ");

        // Generate Alerts Based On New Data
            // Store current data as last for delta based alert comparison.
            activeAlertsLastInterval = activeAlertsInterval;

            // TEMP_LOW
            if (environmentDataInterval.temperatureF < fThreshTempLow) {
                // Clear TEMP_CLEAR alert.
                activeAlertsInterval.bTempClear = false;

                // Set TEMP_LOW alert.
                activeAlertsInterval.bTempLow = true;
            }
            else
            {
                activeAlertsInterval.bTempLow = false;
            }

            // TEMP_HIGH
            if (environmentDataInterval.temperatureF > fThreshTempHigh) {
                // Clear TEMP_CLEAR alert.
                activeAlertsInterval.bTempClear = false;

                // Set TEMP_HIGH alert.
                activeAlertsInterval.bTempHigh = true;
            }
            else 
            {
                activeAlertsInterval.bTempHigh = false;
            }

            // TEMP_DELTA
            // TODO: Consider how / if to do this, given deep sleep plans.

            // TEMP_CLEAR
            // (Dependent on TEMP_LOW & TEMP_HIGH alert evaluation logic occurring first.)
            // Temp Alert Currently False...
            if ((activeAlertsInterval.bTempLow == false) && (activeAlertsInterval.bTempHigh == false)) {            
                // ...AND Temp Alert WAS True
                if ((activeAlertsLastInterval.bTempLow == true) || (activeAlertsLastInterval.bTempHigh == true)) {
                    // Set TEMP_CLEAR alert.
                    activeAlertsInterval.bTempClear = true;
                }
            }
            else 
            {
                activeAlertsInterval.bTempClear = false;
            }

            // POWER_LOSS
            if ((environmentDataInterval.powerSource == POWER_SOURCE_BATTERY) || (environmentDataInterval.powerSource == POWER_SOURCE_UNKNOWN)) {
                // Clear POWER_RESTORE alert.
                activeAlertsInterval.bPowerRestore = false;

                // Set POWER_LOSS alert.
                // TODO: Debounce?
                activeAlertsInterval.bPowerLoss = true;
            }
            else
            {
                activeAlertsInterval.bPowerLoss = false;
            }

            // POWER_RESTORE
            // (Dependent on POWER_LOSS alert evaluation logic occurring first.)
            // Power Loss Alert Currently False...
            if (activeAlertsInterval.bPowerLoss == false) {
                // ...AND Power Loss Alert WAS True
                if (activeAlertsLastInterval.bPowerLoss == true) {
                    // Set POWER_RESTORE alert.
                    activeAlertsInterval.bPowerRestore = true;
                }
            }
            else
            {
                activeAlertsInterval.bPowerRestore = false;
            }

            // BATTERY_LOW
            if (environmentDataInterval.batteryCharge < fThreshBattLow) {
                // Set BATTERY_LOW alert.
                activeAlertsInterval.bBatteryLow = true;
            }
            else
            {
                activeAlertsInterval.bBatteryLow = false;
            }

            // HEARTBEAT
            if ((Time.now() >= (lLastHeartbeatTime + HEARTBEAT_INTERVAL))) {
                activeAlertsInterval.bHeartbeat = true;
                lLastHeartbeatTime = Time.now();
            }
            else
            {
                activeAlertsInterval.bHeartbeat = false;
            }


        // Reset Collect Flag
        bCollectIntervalEnvironmentData = false;
    }


    // === PROCESS ALERTS ===
    // NOTE: Alerts don't mute, for now.

        // TEMP_LOW
        if (activeAlertsInterval.bTempLow == true) {
            // Publish Alert
            publish_alert("TEMP_LOW");

            // Clear Alert
            activeAlertsInterval.bTempLow = false;
        }

        // TEMP_HIGH
        if (activeAlertsInterval.bTempHigh == true) {
            // Publish Alert
            publish_alert("TEMP_HIGH");

            // Clear Alert
            activeAlertsInterval.bTempHigh = false;
        }

        // TEMP_DELTA
        if (activeAlertsInterval.bTempDelta == true) {
            // Publish Alert
            publish_alert("TEMP_DELTA");

            // Clear Alert
            activeAlertsInterval.bTempDelta = false;
        }

        // TEMP_CLEAR
        if (activeAlertsInterval.bTempClear == true) {
            // Publish Alert
            publish_alert("TEMP_CLEAR");

            // Clear Alert
            activeAlertsInterval.bTempClear = false;
        }

        // POWER_LOSS
        if (activeAlertsInterval.bPowerLoss == true) {
            // Publish Alert
            publish_alert("POWER_LOSS");

            // Clear Alert
            activeAlertsInterval.bPowerLoss = false;
        }

        // POWER_RESTORE
        if (activeAlertsInterval.bPowerRestore == true) {
            // Publish Alert
            publish_alert("POWER_RESTORE");

            // Clear Alert
            activeAlertsInterval.bPowerRestore = false;          
        }

        // BATTERY_LOW
        if (activeAlertsInterval.bBatteryLow == true) {
            // Publish Alert
            publish_alert("BATTERY_LOW");

            // Clear Alert
            activeAlertsInterval.bBatteryLow = false;
        }

        // HEARTBEAT
        if (activeAlertsInterval.bHeartbeat == true) {
            // Publish Alert
            publish_alert("HEARTBEAT");

            // Clear Alert
            activeAlertsInterval.bHeartbeat = false;
        }


}   // END loop


// 
int publish_alert(String alertType) {
    // Variable Declarations
    String body = "Cloud SMS Test";
    String batteryState = battery_state_cast(environmentDataInterval.batteryState);
    String powerSource = power_source_cast(environmentDataInterval.powerSource);

    // Detect manual function calls.
    if (alertType.length()  == 0) {
        alertType = "DEBUG";
    }

    // Build & Format SMS Body
    body = String::format("[ %s ]\nAlert: %s\nTemp: %.1fF\nHumidity: %.1f%%\nBatt: %.1f%%\nBatt State: %s\nPWR SRC: %s\nFW: %s\n%s\n", SECRET_LOCATION, alertType.c_str(), environmentDataInterval.temperatureF, environmentDataInterval.humidity, environmentDataInterval.batteryCharge, batteryState.c_str(), powerSource.c_str(), FW_VERSION, environmentDataInterval.timeString.c_str());


    // Throttle Alert Publishing
    delay(ALERT_THROTTLE_DELAY);

    // JSON Writer Example: https://github.com/rickkas7/JsonParserGeneratorRK/blob/master/examples/2-generator/2-generator-JsonParserGeneratorRK.cpp
    // {{Moustache}} templates used to populate To/From/Body form fields in Twilio API call.
    JsonWriterStatic<256> jwA;
    JsonWriterStatic<256> jwB;
    {
        JsonWriterAutoObject obj(&jwA);

        jwA.insertKeyValue("SMS_TO", SECRET_SMS_TO_A);
        jwA.insertKeyValue("SMS_FROM", SECRET_SMS_FROM);
        jwA.insertKeyValue("SMS_BODY", body);
    }

    {
        JsonWriterAutoObject obj(&jwB);

        jwB.insertKeyValue("SMS_TO", SECRET_SMS_TO_B);
        jwB.insertKeyValue("SMS_FROM", SECRET_SMS_FROM);
        jwB.insertKeyValue("SMS_BODY", body);
    }

    // Publish Alert Data
    Particle.publish("twilio_sms", jwA.getBuffer());
    delay(ALERT_THROTTLE_DELAY);
    Particle.publish("twilio_sms", jwB.getBuffer());
    delay(ALERT_THROTTLE_DELAY);
    
    // Return Length of Alert Body
    return body.length();

}   // END publish_alert


//
void timer_interval_environment_data(void) {
    bCollectIntervalEnvironmentData = true;
}   // END timer_interval_environment_data



int collect_environment_data(String junk) {
    // Local Variable Declarations
    struct environmentData environmentDataReading;

    // Time
    environmentDataReading.time             = Time.now();
    environmentDataReading.timeString       = Time.timeStr();
    environmentDataReading.timeValid        = Time.isValid();

    // System Power
    environmentDataReading.powerSource      = System.powerSource();
    environmentDataReading.batteryState     = System.batteryState();
    environmentDataReading.batteryCharge    = System.batteryCharge();

    // Temperature & Humidity
    environmentDataReading.temperatureF     = C_TO_F(Si7021.readTemperature());
    environmentDataReading.humidity         = Si7021.readHumidity();

    // Light Level
    environmentDataReading.lightLevel       = analogRead(PIN_LIGHT_SEN);

    // Save Last Interval Reading & Save New Data
    environmentDataLastInterval = environmentDataInterval;
    environmentDataInterval = environmentDataReading;

    // Return Current Temperature (cast to int)
    return (int)environmentDataReading.temperatureF;

}   // END collect_environment_data


//
String power_source_cast(int intPowerSource) {
    // https://docs.particle.io/cards/firmware/system-calls/powersource/

    String strPowerSource = "NONE_ERR";

    switch (intPowerSource) {
        case POWER_SOURCE_UNKNOWN:      // 0
        strPowerSource = "UNKNOWN";
        break;

        case POWER_SOURCE_VIN:          // 1
        strPowerSource = "VIN";
        break;

        case POWER_SOURCE_USB_HOST:     // 2
        strPowerSource = "USB_HOST";
        break;

        case POWER_SOURCE_USB_ADAPTER:  // 3
        strPowerSource = "USB_ADAPTER";
        break;

        case POWER_SOURCE_USB_OTG:      // 4
        strPowerSource = "USB_OTG";
        break;

        case POWER_SOURCE_BATTERY:      // 5
        strPowerSource = "BATTERY";
        break;
    }

    return strPowerSource;
}   // END power_source_cast


String battery_state_cast(int intBatteryState) {
    // https://docs.particle.io/cards/firmware/system-calls/batterystate/

    String strBatteryState = "NONE_ERR";

    switch (intBatteryState) {
        case BATTERY_STATE_UNKNOWN:         // 0
        strBatteryState = "UNKNOWN";
        break;

        case BATTERY_STATE_NOT_CHARGING:    // 1
        strBatteryState = "NOT_CHARGING";
        break;

        case BATTERY_STATE_CHARGING:        // 2
        strBatteryState = "CHARGING";
        break;

        case BATTERY_STATE_CHARGED:         // 3
        strBatteryState = "CHARGED";
        break;

        case BATTERY_STATE_DISCHARGING:     // 4
        strBatteryState = "DISCHARGING";
        break;

        case BATTERY_STATE_FAULT:           // 5
        strBatteryState = "FAULT";
        break;

        case BATTERY_STATE_DISCONNECTED:    // 6
        strBatteryState = "DISCONNECTED";
        break;
    }

    return strBatteryState;
}

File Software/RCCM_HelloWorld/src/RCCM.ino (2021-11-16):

/*
 * Project: Remote Cabin Climate Monitor (RCCM)
 * Description: A Particle Mesh based environmental sensor board, whose primary purpose is to monitor unoccupied cabin temperatures at Resica Falls Scout Reservation.
 * Author: Z. Cross & D. Gibbons
 * Date: 08Jan2020
 */


// PIN DEFINITIONS
#define PIN_LIGHT_SEN     19  // Internal Light Sensor Signal (Analog)
#define PIN_ADC_1         18  // External GPIO Port Signal
#define PIN_ADC_2         17  // External GPIO Port Signal
#define PIN_PIR           16  // PIR Sensor Port Signal
#define PIN_INT_SIG       15  // Internal Sensor Port Signal
#define PIN_DIP_1         14  // Internal DIP Switch Position 1
#define PIN_DIP_2         13  // Internal DIP Switch Position 2
#define PIN_DIP_3         12  // Internal DIP Switch Position 3
#define PIN_DIP_4         11  // Internal DIP Switch Position 4
#define PIN_UART_Rx       10  // External UART Port Signal Rx
#define PIN_UART_Tx       9   // External UART Port Signal Tx

#define PIN_S1            8   // Internal Pushbutton S1
#define PIN_S2            7   // Internal Pushbutton S2
#define PIN_LED_HEARTB    4   // Internal Heartbeat LED (Green)
#define PIN_LED_LOCATE    5   // Internal Locate LED (Red)
#define PIN_LED_ACTIVITY  6   // Internal Activity LED (Red)
#define PIN_1W            3   // External 1-Wire Bus Signal
#define PIN_DIP_5         2   // Internal DIP Switch Position 5



// INCLUDES
#include "Si7021_MultiWire.h"   // Si7021
#include "DS18B20.h"            // DS18B20
#include <math.h>               // DS18B20


// FUNCTION PROTOTYPES
void self_test_blocking(void);
void ledFlutter(int pin, int time, int loops);
void allOn(void);
void allOff(void);
double getTemp(void);


// Initialize objects from the lib
Si7021_MultiWire sensor = Si7021_MultiWire(Wire1);


// DS18B20
const int      MAXRETRY          = 4;
const uint32_t msSAMPLE_INTERVAL = 2500;
const uint32_t msMETRIC_PUBLISH  = 30000;

DS18B20  ds18b20(PIN_1W, true); //Sets Pin D2 for Water Temp Sensor and 
                            // this is the only sensor on bus
char     szInfo[64];
double   celsius;
double   fahrenheit;
uint32_t msLastMetric;
uint32_t msLastSample;


// 
void setup() {
    // Internal Sensor Expansion
    pinMode(PIN_INT_SIG, INPUT);

    // PIR Sensor
    pinMode(PIN_PIR, INPUT);

    // Internal Switches
    pinMode(PIN_DIP_1,  INPUT_PULLUP);
    pinMode(PIN_DIP_2,  INPUT_PULLUP);
    pinMode(PIN_DIP_3,  INPUT_PULLUP);
    pinMode(PIN_DIP_4,  INPUT_PULLUP);
    pinMode(PIN_DIP_5,  INPUT_PULLUP);
    pinMode(PIN_S1,     INPUT_PULLUP);
    pinMode(PIN_S2,     INPUT_PULLUP);

    // Internal Status LEDs
    pinMode(PIN_LED_HEARTB,     OUTPUT);
    pinMode(PIN_LED_LOCATE,     OUTPUT);
    pinMode(PIN_LED_ACTIVITY,   OUTPUT);

    // Internal Sensor Interfaces
    pinMode(PIN_PIR,        INPUT_PULLUP);
    pinMode(PIN_INT_SIG,    INPUT_PULLUP);

    // External Sensor Interfaces
    pinMode(PIN_ADC_1,  INPUT_PULLUP);
    pinMode(PIN_ADC_2,  INPUT_PULLUP);
    pinMode(PIN_1W,     INPUT_PULLUP);

    // Initialize Debug UART
    Serial.begin(9600);
    Serial.println("=== RCCM STARTUP ===");

    // I2C Bus Initizalition
    Serial.println(sensor.begin());


    // Run Self Test
    //self_test_blocking();

}

// 
void loop() {

    //
    waitFor(Serial.isConnected, 30000);
    //self_test_blocking();

    // Module Testing
    static bool flag = false;
    while (digitalRead(PIN_S1) == HIGH);
    if (flag == false)
    {
        ledFlutter(PIN_LED_HEARTB, 50, 10);
        flag = true;
        Particle.publish("SendGrid-SendEmail", "{'email_body':Purple789}", PRIVATE);
    }
    
}


void self_test_blocking() {

    // SELF-TEST START
    Serial.println("=== RCCM SELF TEST START ===");
    for (int i = 10; i > 0; i--)
    {
        Serial.println(i);
        delay(500);
    }
    Serial.println("");
    Serial.println("");
    Serial.println("");
    delay(3000);


    // EXTERNAL 1-W DS18B20 SENSOR TEST
    Serial.println("TEST - 1-W DS18B20");
    //Serial.println("      Info: Confirm valid temperature readings (10x repeat, once per second).");
    for (int i = 0; i < 10; i++)
    {
        getTemp();
        //Serial.print("Temperature:    ");
        Serial.println(fahrenheit, 2);
        delay(1000);
    }
    Serial.println("");
    Serial.println("");
    Serial.println("");


    // Si7021 SENSOR TEST
    Serial.println("TEST - Si7021");
    //Serial.println("      Info: Confirm valid temperature and humidity readings (10x repeat, once per second).");
    for (int i = 0; i < 10; i++)
    {
        Serial.print("Humidity:    ");
        Serial.print(sensor.getRH(), 2);
        Serial.print("    Temperature: ");
        Serial.println(sensor.readTempF(), 2);
        delay(1000);
    }
    Serial.println("");
    Serial.println("");
    Serial.println("");
    

    // AMBIENT LIGHT SENSOR TEST
    Serial.println("TEST - Ambient Light Sensor");
    //Serial.println("      Info: Confirm valid ambient light readings (10x repeat, once per second).");
    for (int i = 0; i < 10; i++)
    {
        int lightLevel = 0;
        lightLevel = analogRead(PIN_LIGHT_SEN);
        Serial.print("Light Level:    ");
        Serial.println(lightLevel);
        delay(1000);
    }
    Serial.println("");
    Serial.println("");
    Serial.println("");


    // ONBOARD SWITCH TEST
    Serial.println("TEST - Onboard Switches");
    Serial.println("        Info: Toggle S1, S2, and dip 1-5 in order.");

    while (digitalRead(PIN_S1) == HIGH);
    Serial.println("        S1: Pass");
    ledFlutter(PIN_LED_HEARTB, 50, 10);
    allOff();

    while (digitalRead(PIN_S2) == HIGH);
    Serial.println("        S2: Pass");
    ledFlutter(PIN_LED_HEARTB, 50, 10);
    allOff();

    while (digitalRead(PIN_DIP_1) == HIGH);
    while (digitalRead(PIN_DIP_1) == LOW);
    while (digitalRead(PIN_DIP_1) == HIGH);
    Serial.println("        DIP1: Pass");
    ledFlutter(PIN_LED_HEARTB, 50, 10);
    allOff();

    while (digitalRead(PIN_DIP_2) == HIGH);
    while (digitalRead(PIN_DIP_2) == LOW);
    while (digitalRead(PIN_DIP_2) == HIGH);
    Serial.println("        DIP2: Pass");
    ledFlutter(PIN_LED_HEARTB, 50, 10);
    allOff();

    while (digitalRead(PIN_DIP_3) == HIGH);
    while (digitalRead(PIN_DIP_3) == LOW);
    while (digitalRead(PIN_DIP_3) == HIGH);
    Serial.println("        DIP3: Pass");
    ledFlutter(PIN_LED_HEARTB, 50, 10);
    allOff();

    while (digitalRead(PIN_DIP_4) == HIGH);
    while (digitalRead(PIN_DIP_4) == LOW);
    while (digitalRead(PIN_DIP_4) == HIGH);
    Serial.println("        DIP4: Pass");
    ledFlutter(PIN_LED_HEARTB, 50, 10);
    allOff();

    while (digitalRead(PIN_DIP_5) == HIGH);
    while (digitalRead(PIN_DIP_5) == LOW);
    while (digitalRead(PIN_DIP_5) == HIGH);
    Serial.println("        DIP5: Pass");
    ledFlutter(PIN_LED_HEARTB, 50, 10);
    allOff();

    Serial.println("");
    Serial.println("");
    Serial.println("");
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

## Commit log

2019-12-23 Initial commit of Rev0 schematic.
    [RCCM_BillOfMaterials_Rev0.csv]
2019-12-23 Rev0 Schematic PDF Export
2019-12-23 Rev0.1 - PCB layout and routing draft.
    [219-5poles.stp, 395121003.stp, 395121004.stp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]
2019-12-24 Rev1.0 - Prototype Manufacturing Release
    [BoardOutline.gbr, Bottom.gbr, BottomAssy.gbr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]
2019-12-24 Rev1.0 - Prototype Manufacturing Release File Update (Corrected PCB silk error.)
    [BoardOutline.gbr, Bottom.gbr, BottomAssy.gbr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]
2019-12-24 Image file-name update & addition of DipTrace library files.
    [219-5poles.stp, 395121003.stp, 395121004.stp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]
2019-12-31 Updated schematic (v1.1) to include 4 position pluggable Molex screw terminals to mate with J10 and J13.
    [RCCM_BillOfMaterials_Rev1.0.csv, RCCM_BillOfMaterials_Rev1.1.csv]
2021-11-16 Added current enclosure design files. Re-organized 'Hardware' directory accordingly.
    [219-5poles.stp, 395121003.stp, 395121004.stp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]
2021-12-21 Send SMS with custom To/From/Body directly from Particle device proof of concept.
2022-01-08 Fixed heartbeat issue; 0.1.3 RELEASE.
    [RCCM.ino]
2022-01-10 2nd SMS Rx Bugfix - 0.1.4 RELEASE
    [RCCM.ino]
